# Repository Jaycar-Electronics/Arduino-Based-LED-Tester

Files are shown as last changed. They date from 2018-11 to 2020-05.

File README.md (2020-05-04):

# Arduino Based LED Tester

A handy little tool that can help you out if you work with LED’s a lot, especially if you are always trying to work out the right resistor to make them work. The idea has been shamelessly borrowed from Dave Cook’s model at http://robotroom.com/LED-Tester-Pro-1.html. I’ve written the code from scratch to suit the parts we have available in the Duinotech range.

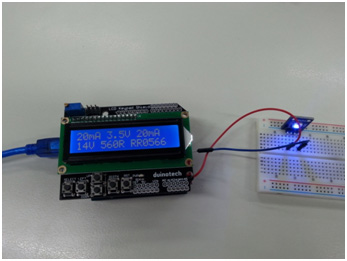
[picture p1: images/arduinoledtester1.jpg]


The display shows target current, LED forward voltage, actual test current on the first line and target supply voltage, suggested resistance and suggested Jaycar part number from the ½W range. If the resistor would dissipate more than half a watt, a `P` flashes on the top line to let you know you might need to choose a more powerful resistor.

The other good thing about this project is that apart from the custom shield we’re going to build out of the prototyping shield, all the boards can just be pulled apart and reused.

## Bill of Materials

| Qty | Code | Description |
| --- | --- | --- |
| 1 | [XC4410](http://jaycar.com.au/p/XC4410) | UNO Board |
| 1 | [XC4482](http://jaycar.com.au/p/XC4482) | prototyping shield |
| 1 | [XC4454](http://jaycar.com.au/p/XC4454) | LCD controller |
| 1 | [RR0538](http://jaycar.com.au/p/RR0538) | 39R 1/2W Resistor |
| 1 | [RR0524](http://jaycar.com.au/p/RR0524) | 10R 1/2W Resistor |
| 1 | [RE6194](http://jaycar.com.au/p/RE6194) | 470u 16V electrolytic capacitor |

I’ve used a couple of jumper wires as test leads, but any old wire should do. You could even use test leads with sockets in the end (like WC6028) and push the legs of the LED’s in.

## Connection Table

| Connections | | |
| --- | --- | --- |
| 470uF capacitor | A2  | GND |
| 39R Resistor | A2  | D3  |
| 10R Resistor | A2  | A3  |
| Positive test Lead | D3  | |
| Negative Test Lead | GND | |

## Assembly

Here is the circuit diagram of the custom shield:

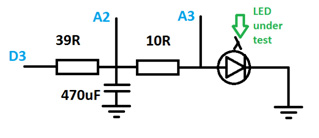
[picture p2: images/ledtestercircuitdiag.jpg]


And what it looks like assembled:

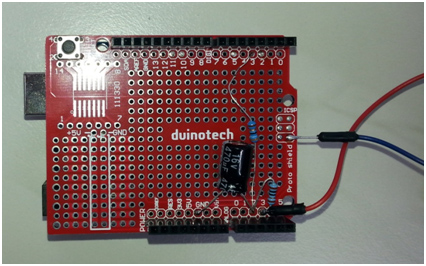
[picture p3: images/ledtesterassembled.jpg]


Note that I’ve used the GND connection on the ICSP header for the test lead. There should be enough length in the component legs that extra wire isn’t needed. The only other thing to watch out for is that the negative (white stripe) side of the capacitor goes to GND.

When this is assembled, connect the Uno to the bottom of the new shield and the LCD shield to the top.

## Programming

If you haven’t already, download and install the Arduino IDE from https://www.arduino.cc/en/Main/Software, and check that the drivers are installed for the Uno board.

Open the sketch file in the Arduino IDE and upload it to the Uno, making sure Uno is selected from Tools>Board, and that the correct serial port for the Uno is selected from Tools>Port.

## Use

After this, the Arduino LED Tester should spring into life. With no LED attached, it will not show a resistor value. Connect an LED between the test leads and the LED will light up, and the display will show its characteristics operating from a 14V supply at 10mA. The target voltage can be changed between 1V and 99V with the up and down buttons on the display, and the left and right buttons change the target current (up to 20mA).

## Future Improvements

With only software changes, the Tester could also be modified to test other 2-legged components, so it might be possible to use it as a capacitance meter. Of course, it can tell you the forward voltage of regular diodes in its current form.

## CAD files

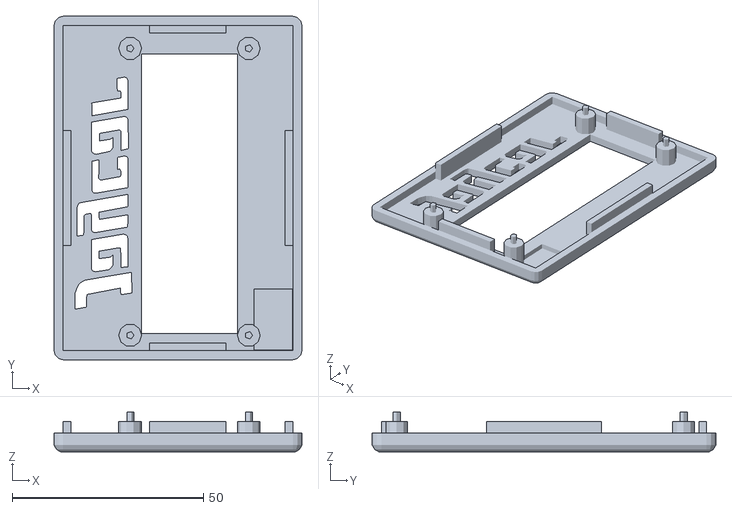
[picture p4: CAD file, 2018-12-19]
stl/Duinotech Box Lid.stl
64.8 x 89.8 x 10.4

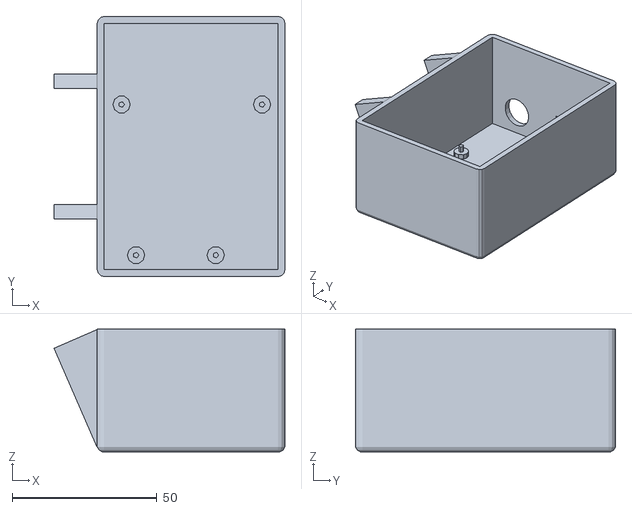
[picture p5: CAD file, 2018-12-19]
stl/Duinotech Box with Legs.stl
79.7 x 89.8 x 42.4

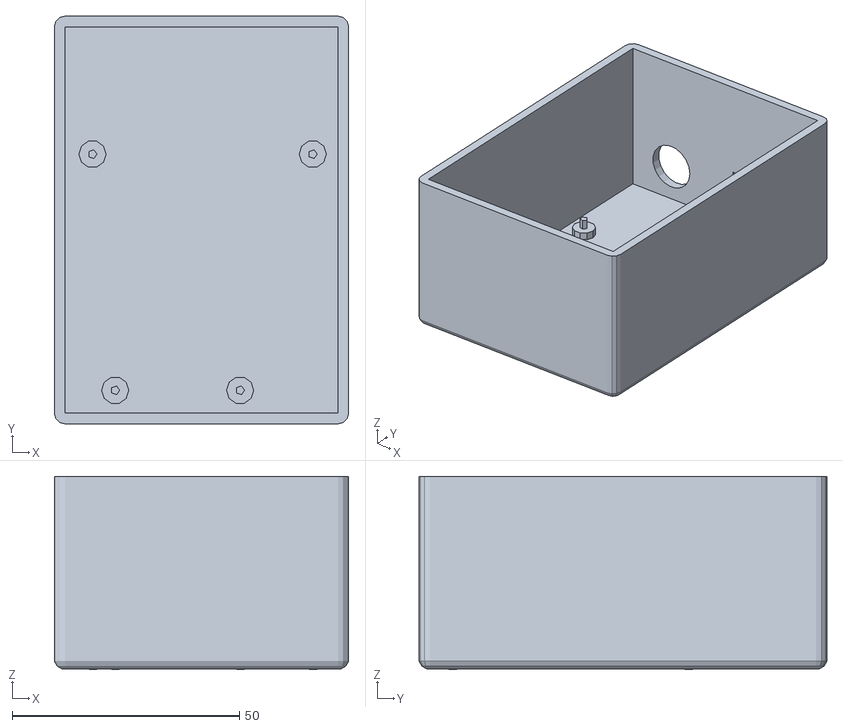
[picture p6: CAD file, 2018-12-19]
stl/Duinotech Box.stl
64.8 x 89.8 x 42.5

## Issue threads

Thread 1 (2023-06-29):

Does not compile in either 1.8 or 2.x IDE - I have a partial fix

kptb, 2023-06-29:
I won't claim I knew how to fix this, and it's beyond me technically, but just as I was close to giving up, some trial and error tweaks based on some reading got it working....at least compiling and doing most of what we expect. I don't have buttons set up, so I am not 100% sure, but I think we just lose the part number....and that's what jaycar store staff are for ;)

I have listed the changes below -  I can submit a PR, but I'd have to change some pins etc back as I have changed assignments to work with my non shield setup for the LCD. It might just be easier for you to add these changes or fix yourselves if you were unaware.

**Errors:**

`\Documents\Arduino\Projects\Examples-and-Demos\Arduino-Based-LED-Tester-master\ledtest\ledtest.ino:41:6: error: 'long int rindex' redeclared as different kind of symbol
 long rindex;    //index of selected resistor in rvals[]
      ^~~~~~
In file included from c:\users\kevin\appdata\local\arduino15\packages\arduino\tools\arm-none-eabi-gcc\7-2017q4\arm-none-eabi\include\string.h:24:0,
                 from C:\Users\kevin\AppData\Local\Arduino15\packages\arduino\hardware\samd\1.8.13\cores\arduino/api/String.h:28,
                 from C:\Users\kevin\AppData\Local\Arduino15\packages\arduino\hardware\samd\1.8.13\cores\arduino/api/IPAddress.h:24,
                 from C:\Users\kevin\AppData\Local\Arduino15\packages\arduino\hardware\samd\1.8.13\cores\arduino/api/ArduinoAPI.h:30,
                 from C:\Users\kevin\AppData\Local\Arduino15\packages\arduino\hardware\samd\1.8.13\cores\arduino/Arduino.h:23,
                 from C:\Users\kevin\AppData\Local\Temp\arduino\sketches\28BADF18DEA75BBA8D9B1B1C3C4CFB9B\sketch\ledtest.ino.cpp:1:
c:\users\kevin\appdata\local\arduino15\packages\arduino\tools\arm-none-eabi-gcc\7-2017q4\arm-none-eabi\include\strings.h:65:7: note: previous declaration 'char* rindex(const char*, int)'
 char *rindex(const char *, int) __pure;   /* LEGACY */
       ^~~~~~
\Documents\Arduino\Projects\Examples-and-Demos\Arduino-Based-LED-Tester-master\ledtest\ledtest.ino: In function 'void loop()':
\Documents\Arduino\Projects\Examples-and-Demos\Arduino-Based-LED-Tester-master\ledtest\ledtest.ino:73:31: error: assignment of function 'char* rindex(const char*, int)'
     if(rvals[i]>=rval){rindex=i;rval=rvals[rindex];i=RCOUNT+1;rvalid=1;}
                               ^
\Documents\Arduino\Projects\Examples-and-Demos\Arduino-Based-LED-Tester-master\ledtest\ledtest.ino:73:31: error: cannot convert 'int' to 'char*(const char*, int)' in assignment
\Documents\Arduino\Projects\Examples-and-Demos\Arduino-Based-LED-Tester-master\ledtest\ledtest.ino:73:50: error: invalid types 'long int [121][char*(const char*, int)]' for array subscript
     if(rvals[i]>=rval){rindex=i;rval=rvals[rindex];i=RCOUNT+1;rvalid=1;}
                                                  ^
\Documents\Arduino\Projects\Examples-and-Demos\Arduino-Based-LED-Tester-master\ledtest\ledtest.ino: In function 'void dolcd()':
\Documents\Arduino\Projects\Examples-and-Demos\Arduino-Based-LED-Tester-master\ledtest\ledtest.ino:124:26: error: invalid conversion from 'char* (*)(const char*, int)' to 'int' [-fpermissive]
     lcdprintpartno(rindex);    //resistor part no (6 characters)
                          ^
\Documents\Arduino\Projects\Examples-and-Demos\Arduino-Based-LED-Tester-master\ledtest\ledtest.ino:142:6: note:   initializing argument 1 of 'void lcdprintpartno(int)'
 void lcdprintpartno(int index){
      ^~~~~~~~~~~~~~

exit status 1

Compilation error: 'long int rindex' redeclared as different kind of symbol`

**Partial Fix:**

- Move  `long rindex;    //index of selected resistor in rvals[] ` declaration to the main _void loop()_
- Commentout `lcdprintpartno(rindex);    //resistor part no (6 characters)` from `void dolcd(){`. This removes the part number return.

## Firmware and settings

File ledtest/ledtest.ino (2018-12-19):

/*
Arduino LED Tester
DPIN--39R--+--10R---TESTLED---GND
           |      |         |
          470u    ATOP     ABOT
           |
          GND

 Measures LED characteristics by charging up the cap to deliver target current and find forward voltage
 From target current, we can calculate R to be used with a design supply voltage and a matching part number.
  */
#include <LiquidCrystal.h>
//pin defs to suit LCD Shield
LiquidCrystal lcd(8, 9, 4, 5, 6, 7);
//lcd update interval
#define LCDINT 500
//key check interval
#define KEYINT 200
//pin for buttons
#define KEYPIN A0
//button constants
#define btnRIGHT  6
#define btnUP     5
#define btnDOWN   4
#define btnLEFT   3
#define btnSELECT 2
#define btnNONE   (-1)

//Globals for display
long itest=10;    //test current, in mA
long vset =14000;  //display voltage in mV
long vled,vrr,irr,pset;  //LED voltage, Resistor voltage, resistor current, display power
//resistors in Jaycar 1/2 W range, part nos start at RR0524 for 10R
#define RCOUNT 121
long rvals[]={10,11,12,13,15,16,18,20,22,24,27,30,33,36,39,43,47,51,56,62,68,75,82,91,100,110,120,130,150,160,180,200,220,240,270,300,330,360,390,430,470,510,560,620,680,750,820,910,1000,1100,1200,1300,1500,1600,1800,2000,2200,2400,2700,3000,3300,3600,3900,4300,4700,5100,5600,6200,6800,7500,8200,9100,10000,11000,12000,13000,15000,16000,18000,20000,22000,24000,27000,30000,33000,36000,39000,43000,47000,51000,56000,62000,68000,75000,82000,91000,100000,110000,120000,130000,150000,160000,180000,200000,220000,240000,270000,300000,330000,360000,390000,430000,470000,510000,560000,620000,680000,750000,820000,910000,1000000};
long lastlcd=0;  //time of last lcd update
long lastkey=0;  //time of last key check
int lcdflash=0;  //lcd flashing phase variable
long pdes;
long rval;      //calculated resistor value for display
long rindex;    //index of selected resistor in rvals[]
int pwmout=0;    //pwm output of current driver
int rvalid=0;    //flag if resistor value is valid 
//pins for test interface
#define ATOP A2
#define ABOT A3
#define DPIN 3
#define OSAMP 16

void setup() {
  lcd.begin(16, 2);        //lcd 
  pinMode(DPIN,OUTPUT);    //pwm pin
}

void loop() {
  long atop,abot,arr;      //analog sample values
  rvalid=0;                //set flag to not valid
  atop=analogoversample(ATOP,OSAMP)/OSAMP;
  abot=analogoversample(ABOT,OSAMP)/OSAMP;  
  arr=atop-abot;      //this is the analog value across the 10R sense resistor
  if(arr<0){arr=0;}    //sanity check
  vled=abot*5000/1023;  //5000mV=1023 => voltage across LED
  vrr=arr*5000/1023;    //voltage across sense resistor
  irr=vrr/10;     //led and resistor current in mA (cos it's a 10R resistor)
    
  if(irr<itest){pwmout++;if(pwmout>255){pwmout=255;}}    //ramp up current if too low
  if(irr>itest){pwmout--;if(pwmout<0){pwmout=0;}}        //ramp down if too high
  if(irr>24){pwmout=pwmout-5;if(pwmout<0){pwmout=0;}}    //ramp down quick if too too high
  if(irr>itest*3){pwmout=pwmout-5;if(pwmout<0){pwmout=0;}}    //ramp down quick if too too high
  analogWrite(DPIN,pwmout);                              //output new PWM
  rval=(vset-vled)/itest;                                //mV/mV => ohms resistance of display resistor
  for(int i=0;i<RCOUNT;i++){                             //find next highest E24 value
    if(rvals[i]>=rval){rindex=i;rval=rvals[rindex];i=RCOUNT+1;rvalid=1;}
  }
  if(abs(irr-itest)>(itest/5)+1){rvalid=0;}              //has current settled within 20%?
  if(vled>vset){rvalid=0;}                               //if vled>vset, no valid resistor exists
  pset=0;        //work out dissipation in ballast resistor if valid)
  if(rvalid){pset=itest*itest*rval;}      //this will be in microwatts (milliamps squared)
  
  if(millis()-lastlcd>LCDINT){      //check if display due to be updated
    lastlcd=millis();
    dolcd();        //update display
    lcdflash=1-lcdflash;  //toggle flash variable
    }
  if(millis()-lastkey>KEYINT){    //check if keys due to be checked
    lastkey=millis();
    dobuttons();
    }
    delay(1);
}        //end of loop

void dolcd(){
  lcd.setCursor(0,0);    //first line
  //milliamps
  if(lcdflash||rvalid){        //show if correct if on flashing phase
    if(itest>9){lcd.write(((itest/10)%10)+'0');}else{lcd.write(' ');}    //blank tens if zero
    lcd.write((itest%10)+'0');
  }
  else{      //blank if not
    lcd.write(' ');lcd.write(' ');
  }
    lcd.write('m');lcd.write('A');lcd.write(' ');
  //VLED
  lcd.write(((vled/1000)%10)+'0');
  lcd.write('.');
  lcd.write(((vled/100)%10)+'0');
  lcd.write('V');lcd.write(' ');

  //actual LED current
  if(irr>9){lcd.write(((irr/10)%10)+'0');}else{lcd.write(' ');}    //blank tens if zero
  lcd.write((irr%10)+'0');
  lcd.write('m');lcd.write('A');lcd.write(' ');
  if((pset>499999)&&(lcdflash)){lcd.write('P');}else{lcd.write(' ');} //flash P if power above 1/2 watt
  
  lcd.setCursor(0,1);   //second line
  //
  if(vset>9999){lcd.write(((vset/10000)%10)+'0');}else{lcd.write(' ');}    //tens of vset, blank if zero
  lcd.write(((vset/1000)%10)+'0');      //units of vset
  lcd.write('V');lcd.write(' ');
  
  if(rvalid){
    lcdprintrval(rval);  //resistor value (4 characters)
    lcd.write(' ');
    lcdprintpartno(rindex);    //resistor part no (6 characters)
    if(pset>499999){lcd.write('!');}else{lcd.write(' ');} //show ! if power above 1/2 watt
  }else{
    lcd.write(' ');
    lcd.write('-');
    lcd.write('-');
    lcd.write('-');
    lcd.write(' ');
    lcd.write('-');
    lcd.write('-');
    lcd.write('-');
    lcd.write('-');
    lcd.write('-');
    lcd.write('-');
    lcd.write(' ');
  }    
}

void lcdprintpartno(int index){
  //part number
  lcd.write('R');
  lcd.write('R');
  lcd.write('0');
  lcd.write((((index+524)/100)%10)+'0');      //part no's start at RR0524 for 10R
  lcd.write((((index+524)/10)%10)+'0');
  lcd.write((((index+524))%10)+'0');
}

void lcdprintrval(long rval){        //print a value in 10k0 format, always outputs 4 characters
  	long mult=1;
	long modval;
	if(rval>999){mult=1000;}
	if(rval>999999){mult=1000000;}
	modval=(10*rval)/mult;		//convert to final format, save a decimal place
	if(modval>999){		//nnnM
		lcd.write(((modval/1000)%10)+'0');
		lcd.write(((modval/100)%10)+'0');
		lcd.write(((modval/10)%10)+'0');
		lcdprintmult(mult);
			}else{
	if(modval>99){		//nnMn
		lcd.write(((modval/100)%10)+'0');
		lcd.write(((modval/10)%10)+'0');
		lcdprintmult(mult);
		lcd.write(((modval)%10)+'0');
			}else{	//_nMn
		lcd.write(' ');
		lcd.write(((modval/10)%10)+'0');
		lcdprintmult(mult);
		lcd.write(((modval)%10)+'0');
    }
  }
}
void lcdprintmult(long mult){      //helper function to print multiplier
	switch (mult){
	case 1:	lcd.print('R');break;
	case 1000:	lcd.print('k');break;
	case 1000000:	lcd.print('M');break;
	default:	lcd.print('?');break;
  }
}
int read_LCD_buttons(){
  int adc_key_in    = 0;
  adc_key_in = analogRead(KEYPIN);      // read the value from the sensor 
  delay(5); //switch debounce delay. Increase this delay if incorrect switch selections are returned.
  int k = (analogRead(KEYPIN) - adc_key_in); //gives the button a slight range to allow for a little contact resistance noise
  if (5 < abs(k)) return btnNONE;  // double checks the keypress. If the two readings are not equal +/-k value after debounce delay, it tries again.
  // my buttons when read are centered at these valies: 0, 144, 329, 504, 741
  // we add approx 50 to those values and check to see if we are close
  if (adc_key_in > 1000) return btnNONE; // We make this the 1st option for speed reasons since it will be the most likely result
  if (adc_key_in < 50)   return btnRIGHT;  
  if (adc_key_in < 195)  return btnUP; 
  if (adc_key_in < 380)  return btnDOWN; 
  if (adc_key_in < 555)  return btnLEFT; 
  if (adc_key_in < 790)  return btnSELECT;   
  return btnNONE;  // when all others fail, return this...
}
void dobuttons(){      //updates variables. debounces by only sampling at intervals
    int key;
    key = read_LCD_buttons();
    if(key==btnLEFT){itest=itest-1;if(itest<1){itest=1;}}
    if(key==btnRIGHT){itest=itest+1;if(itest>20){itest=20;}}
    if(key==btnUP){vset=vset+1000;if(vset>99000){vset=99000;}}
    if(key==btnDOWN){vset=vset-1000;if(vset<0){vset=0;}}   
}
long analogoversample(int pin,int samples){      //read pin samples times and return sum
  long n=0;
  for(int i=0;i<samples;i++){
    n=n+analogRead(pin);
  }
  return n;
}
